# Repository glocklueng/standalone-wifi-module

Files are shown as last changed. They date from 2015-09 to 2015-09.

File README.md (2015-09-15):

Standalone Wifi IoT Module 
--------------------------

ESP8266 module with battery charge circuit and some basic IO.

*v1 Status*  
- ordered the board Super Swift on 15 Sep 2015
- ordered all the Digikey parts on 15 Sep 2015

This product uses the [ESP8266 ESP-12E](http://www.electrodragon.com/product/esp-12e-esp8266-wifi-board/).

[Schematic PDF](standalone-v1-schematic.pdf)

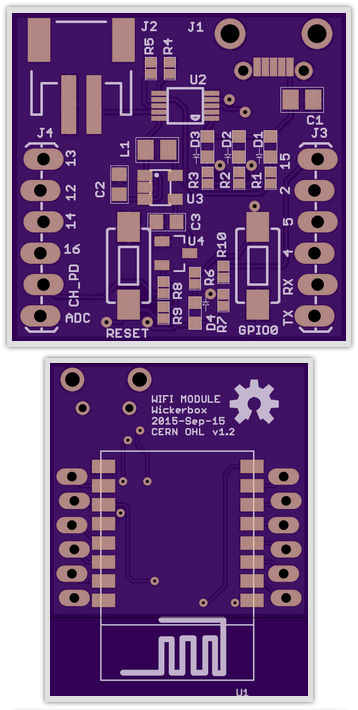
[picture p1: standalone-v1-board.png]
v1 Board Preview


### Bill of Materials

|RefDes|Qty|Description|Mfr|Mfr P/N|Dist|Dist P/N|
|---|---|---|---|---|----|---|
|C1,C2|2|CAP CER 4.7UF 10V 20% X5R 0603|Murata|GRM188R61A475ME15D|Digikey|490-10478-1-ND|
|C3|1|CAP CER 10UF 10V 10% X5R 0603|Murata|GRM188R61A106KE69D|Digikey|490-10474-1-ND|
|D1,D4|2|LED RED DIFFUSED 0603 SMD|OSRAM Opto|LS L296-P2Q2-1-Z|Digikey|475-2761-1-ND|
|D2|1|LED SMARTLED AMBER 615NM 0603|OSRAM Opto|LA L296-Q2R2-1-Z|Digikey|475-2712-1-ND|
|D3|1|LED PURE GREEN 0603 SMD|Stanley|BG1111C-TR|Digikey|404-1005-1-ND|
|J1|1|MICRO B USB RECEPTACLE SMT W/ STUDS|Hirose|ZX62D-B-5P8|Digikey|H11610CT-ND|
|J2|1|CONN HEADER PH SIDE 2POS 2MM SMD|JST|S2B-PH-SM4-TB(LF)(SN)|Digikey|455-1749-1-ND|
|L1|1|FIXED IND 4.7UH 600MA 344.5 MOHM|Taiyo|BRC2012T4R7MD|Digikey|587-2907-1-ND|
|R4|1|RES SMD 2K OHM 1% 1/10W 0402|Panasonic|ERJ-2RKF2001X|Digikey|P2.00KLCT-ND|
|R5,R7-R10|5|RES SMD 10K OHM 1% 1/10W 0402|Panasonic|ERJ-2RKF1002X|Digikey|P10.0KLCT-ND|
|R1-R3|3|RES SMD 150 OHM 1% 1/10W 0402|Panasonic|ERJ-2RKF1500X|Digikey|P150LCT-ND|
|RESET,GPIO0|2|SWITCH TACTILE SPST-NO 0.05A 24V|TE Conn|FSMSM|Digikey|450-1140-ND|
|U1|1|ESP8266 ESP-12E WIFI MODULE|ESP8266|ESP-12E|Electrodragon|NWI1040|
|U2|1|IC LI-ION/LI-POLY CTRLR 10MSOP|Microchip|MCP73833-AMI/UN|Digikey|MCP73833-AMI/UN-ND|
|U3|1|IC REG BST 5V 295MA SYNC SOT-25|Torex|XC9140A501MR-G|Digikey|893-1181-1-ND|
|U4|1|IC REG LDO 3.3V 0.25A SOT23A-3|Microchip|MCP1703T-3302E/CB|Digikey|MCP1703T-3302E/CBCT-ND|

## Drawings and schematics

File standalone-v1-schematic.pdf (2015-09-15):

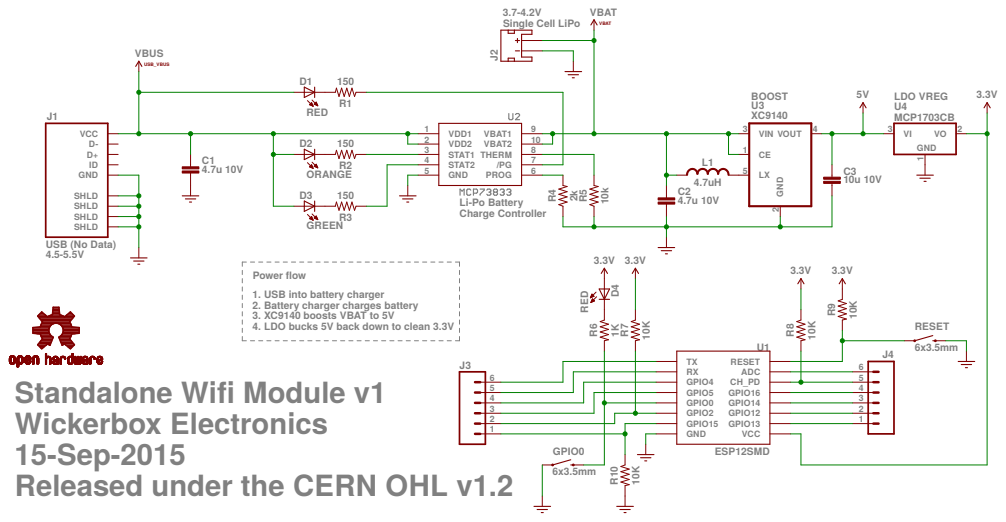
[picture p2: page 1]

Power flow
1. USB into battery charger 2. Battery charger charges battery
3. XC9140 boosts VBAT to 5V
4. LDO bucks 5V back down to clean 3.3V

Standalone Wifi Module v1
Wickerbox Electronics
15-Sep-2015
Released under the CERN OHL v1.2

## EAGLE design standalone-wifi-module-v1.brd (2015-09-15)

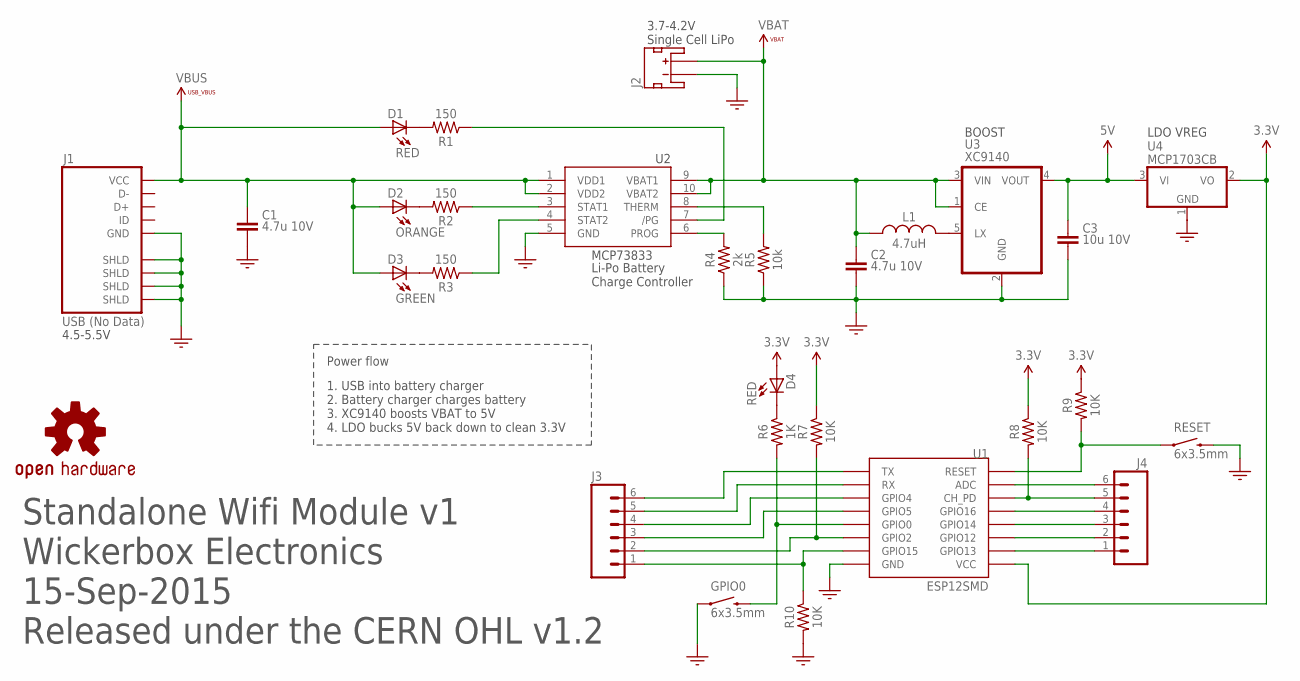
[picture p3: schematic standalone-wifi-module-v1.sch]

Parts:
C1: 4.7u 10V; RLC-0805
C2: 4.7u 10V; RLC-0603
C3: 10u 10V; RLC-0603
D1, D4: RED; LED0603
D2: ORANGE; LED0603
D3: GREEN; LED0603
GPIO0: 6x3.5mm; TACTILE-SWITCH-1101NE
J1: USB (No Data); ZX62D-B-5P8
J2: JST_2MM_MALE; JST-2-SMD
J3, J4: M06LOCK_LONGPADS; 1X06_LOCK_LONGPADS
L1: 4.7uH; RLC-0805
R1, R2, R3: 150; RLC-0402
R4: 2k; RLC-0402
R5: 10k; RLC-0402
R6: 1K; RLC-0402
R7, R8, R9, R10: 10K; RLC-0402
RESET: 6x3.5mm; TACTILE-SWITCH-1101NE
U1: ESP12SMD; ESP12_SMD
U2: MCP73833-UN; MSOP10
U3: XC9140; SOT-25
U4: MCP1703CB; SOT23
U$2: OSHW_LOGO_SYMM; OSHW_LOGO_MED_SYM

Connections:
3.3V: D4.A, R7.1, R8.1, R9.1, U1.VCC, U4.2 (VO)
5V: C3.2 (1), U3.4 (VOUT), U4.3 (VI)
!RESET: R9.2, RESET.1, U1.RESET
ADC: J4.6, U1.ADC
CH_PD: J4.5, R8.2, U1.CH_PD
GND: C1.2, C2.1 (2), C3.1 (2), GPIO0.1, J1.P5 (GND), J1.P$1 (SHLD), J1.P$2 (SHLD), J1.P$3 (SHLD), J1.P$4 (SHLD), J2.1 (-), R4.1, R5.1, R10.2, RESET.2, U1.GND, U2.5 (GND), U3.2 (GND), U4.1 (GND)
GPIO0: GPIO0.2, R6.2, U1.GPIO0
GPIO2: J3.2, R7.2, U1.GPIO2
GPIO4: J3.4, U1.GPIO4
GPIO5: J3.3, U1.GPIO5
GPIO12: J4.2, U1.GPIO12
GPIO13: J4.1, U1.GPIO13
GPIO14: J4.3, U1.GPIO14
GPIO15: J3.1, R10.1, U1.GPIO15
GPIO16: J4.4, U1.GPIO16
unnamed: D4.C, R6.1
unnamed: L1.2, U3.5 (LX)
unnamed: D2.C, R2.2
unnamed: D3.C, R3.2
unnamed: D1.C, R1.2
PG: R1.1, U2.7 (/PG)
PROG: R4.2, U2.6 (PROG)
RX: J3.5, U1.RX
STAT1: R2.1, U2.3 (STAT1)
STAT2: R3.1, U2.4 (STAT2)
THERM: R5.2, U2.8 (THERM)
TX: J3.6, U1.TX
VBAT: C2.2 (1), J2.2 (+), L1.1, U2.9 (VBAT1), U2.10 (VBAT2), U3.1 (CE), U3.3 (VIN)
VBUS: C1.1, D1.A, D2.A, D3.A, J1.P1 (VCC), U2.1 (VDD1), U2.2 (VDD2)

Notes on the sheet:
1. USB into battery charger 2. Battery charger charges battery 3. XC9140 boosts VBAT to 5V 4. LDO bucks 5V back down to clean 3.3V
LDO VREG
Power flow
BOOST
4.5-5.5V
Li-Po Battery Charge Controller
3.7-4.2V Single Cell LiPo
Standalone Wifi Module v1 Wickerbox Electronics 15-Sep-2015 Released under the CERN OHL v1.2

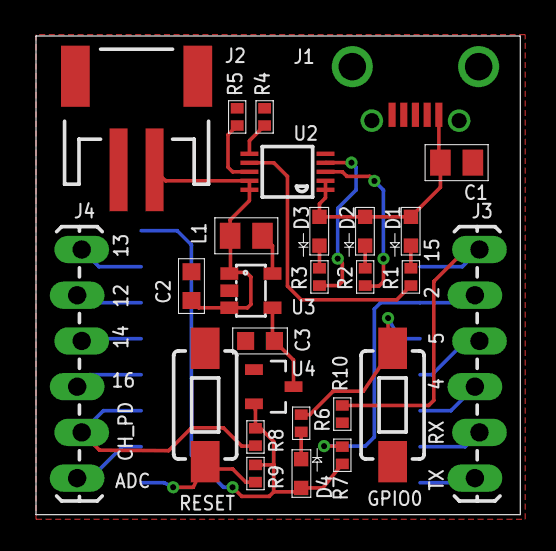
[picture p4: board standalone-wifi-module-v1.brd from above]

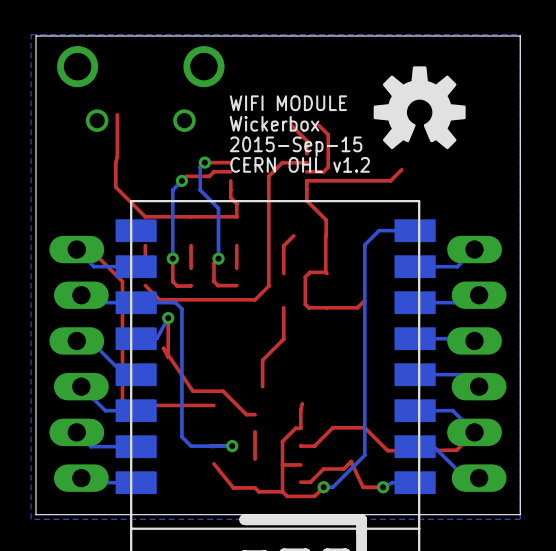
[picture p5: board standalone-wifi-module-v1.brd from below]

Board: 2 copper layers, 26.9 x 26.6 mm, 29 parts (2 on the bottom side), 29 nets.

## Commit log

2015-09-15 First board rev ordered.
    [standalone-wifi-module-v1.brd, standalone-wifi-module-v1.sch]
2015-09-15 Ordered boards from OSH Park, updated full BOM in README.
    [standalone-wifi-module-v1.brd, standalone-wifi-module-v1.sch]

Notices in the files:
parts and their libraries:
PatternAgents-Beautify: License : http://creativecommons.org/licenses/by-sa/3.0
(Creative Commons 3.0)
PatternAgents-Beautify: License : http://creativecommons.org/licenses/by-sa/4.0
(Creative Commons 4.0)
